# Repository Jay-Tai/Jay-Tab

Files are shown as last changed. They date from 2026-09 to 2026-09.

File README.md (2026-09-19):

# The Jay-Tab!

The Jay-Tab!
The Jay-Tab is one of my biggest personal projects! I made it to use it as a small screen to keep on my desk!

I made this project mainly out of personal interest. As to get the money to make this project in real life, I used [Hack club's stardance program!](https://stardance.hackclub.com/)

## Features!

There are many features that are packed into Jay-Tab:

- Beautifully 3D-Printed case!
- 2-Layer PCB enclosing all the hardware!
- Running on the ESP32-S3 WROOM
- 7.5" E-Ink touchscreen display to hold all the features of the Jay-Tab!
- <b>Home screen</b> that shows all you need to know at a glimpse
- <b>Calendar screen</b> that shows all the events happening in your day!
- <b>Timer screen</b> that has a timer that you can play a timer on a dedicated screen on your desk!
- <b>Home control screen</b> that is based off the Govee API, letting you toggle your lights, and change the color!

## CAD

The CAD model is from OnShape. It is made so the screen takes up 95% of the project, along with a stem that has weights inside of it to hold the Jay-Tab.

There are multiple parts, that are all going to be held using multiple screws. The power button is on the right side stem of the project.

### Important note about the CAD!

There is a part in the CAD that is CNCed. The bottom weight is CNCed to make sure that the Jay-Tab is able to stay upright, while also giving a premium feel through weight.There is also another laser-cuttable rubber part that goes on the bottom to stop it from moving.

The Jay-Tab!

## PCB



The PCB is the main hub of the entire project. It is in charge of making the OLED work, running code, powering the project, and the switches. It runs based off of the ESP32-S3 WROOM.

The following image is the schematic:

The schematic

And this is the PCB:
The schematic

## Firmware

The firmware for the project is based off of [python](https://www.python.org/) coding language. I made the UI Drawing Interface by myself, as I couldn't find any good libraries that are simple, and are able to support E-Ink Displays. The firmware includes the following:

- Home page that has a glimpse of your entire day with upcoming events, time, and quick controls.
- Calendar panel that is connected to your Google Calendar that shows all your events in a day
- Timer panel that allows you to create timers
- Smart home panel that connects to the Govee API, allowing you to toggle and change the color of your Govee lights.

Here is what the pages look like when connected to my APIs:

### Home Page:

The schematic

### Calendar:

The schematic

### Timer:

The schematic

### Home Control:

The schematic

## Quick Start

To make your own Jay-Tab, it is <b>crucial</b> that you follow these steps so that everything works with your environment!

<u>1: Create your Google Calendar API!</u>
The first step to making your own Jay-Tab is to create your own Google Calendar API. You can use the Google Cloud Calender API by clicking [here](https://console.cloud.google.com/marketplace/product/google/calendar-json.googleapis.com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). Download the file that has your key, and rename it to <i>calendar_desktop_credentials.json</i>

<u>2: Create your Govee API!</u>
The second step is to create the Govee API! Use the [following guide](https://developer.govee.com/docs/getting-started) to create your own govee API!

Once you get the Govee API, put it in under "apikey"

<u>3: Change your home screen name!</u>
To change the name on the Home Screen, use the adobe illustrator file that is attached under the software folder of the Jay-Tab. This will let you change the name from my name (Jay) to whatever it is!

# BOM

To make your own Jay-Tab, use the BOM under /bom.csv! :D

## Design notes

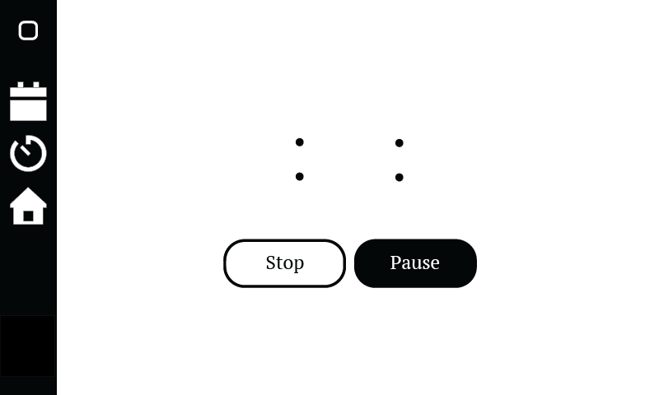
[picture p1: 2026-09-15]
Software/Raw images/New screens/Timer Running.png

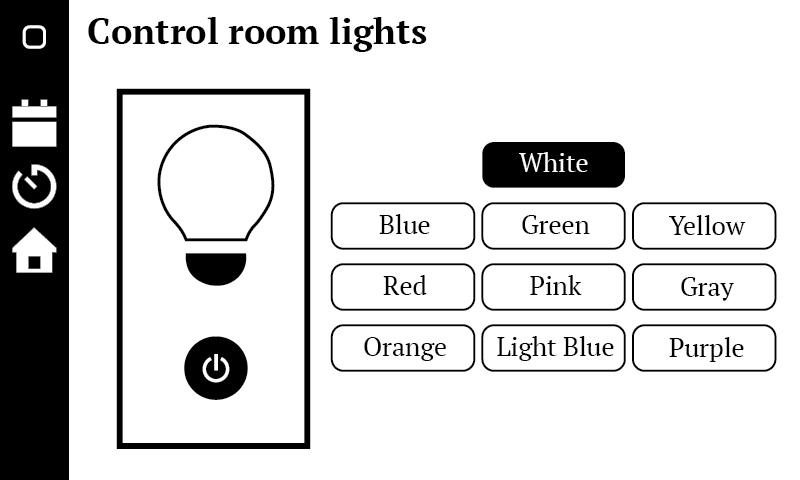
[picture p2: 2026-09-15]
Software/Raw images/New screens/Calendar - Software.png

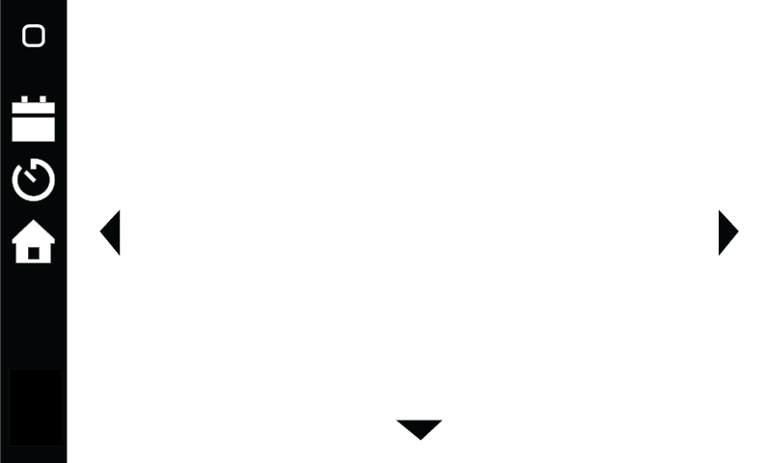
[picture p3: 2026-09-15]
Software/Raw images/New screens/Calendar over 6.png

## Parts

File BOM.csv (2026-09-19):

Item | Description | Quantity | Item Total Price + Tax | Supplier | URL
7.5-Inch Touch E-Paper E-Ink Display | Display | 1 | $57.00 | Goodisplay | https://buy-lcd.com/products/gdey075t7-t01
ESP32-S3-WROOM-1-N16R8 | MCU | 1 | $8.54 | Digikey | https://www.digikey.ca/en/products/detail/espressif-systems/ESP32-S3-WROOM-1-N8/15200089
12-pin 2.5mm pitch JST-XH Horizontal Through-Hole Connector | Display connector to PCB from HAT | 1 | $0.69 | Digikey | https://www.digikey.ca/en/products/detail/jst-sales-america-inc/S12B-XH-A/1651019
EC11 Switch Rotary Encoder | Rotary Encoder | 1 | $3.04 | Digikey | https://www.digikey.ca/en/products/detail/bourns-inc/PEC11R-4220F-S0024/4499660
SPDT Latching Push Switch | Power button | 1 | $9.51 | Amazon | https://www.amazon.ca/Gebildet-Stainless-Latching-12V-24V-Waterproof/dp/B07P7SXCP3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
Custom PCB Printing | Backend PCB | 1 | $9.94 | JLCPCB | https://ibb.co/8nVgBxCD
DESPI-C02 E-Ink Display HAT | Display adapter | 1 | $20.82 | Goodisplay | https://www.good-display.com/product/516.html
CNC for weight | Weight stem | 1 | $79.50 | PcbWay | https://postimg.cc/TywTsFk9
Digikey - FedEx International Priority | Shipping | 1 | $10.73 | Digikey + FedEx | https://ibb.co/r2qRh172
JLC Product Shipping | Shipping | 1 | $10.63 | JLCPCB | https://ibb.co/3Y4qh31H
6-Pin FPC Breakout Board | Amazon | 1 | $8.88 | Amazon | https://www.amazon.ca/uxcell-Converter-Couple-Extend-Adapter/dp/B07RWRK4WX
Printing Legion 3DP Fee | 3D Printing fee | 1 | $20 | Hack Club | N/A
USB-C 12-Pin SMD | USB-C | 1 | $1.77 | Digikey | https://www.digikey.ca/en/products/detail/on-shore-technology-inc/USB-CB16HTBTR/18649611
5.2kΩ Resistor | Resistor type 1 | 2 | $0.36 | Digikey | https://www.digikey.ca/en/products/detail/stackpole-electronics-inc/CF14JT10K0/1741265
10uF Capacitor | Capacitor | 2 | $8.59 | Digikey | https://www.digikey.ca/en/products/detail/vishay-beyschlag-draloric-bc-components/MAL202138109E3/262969
4.7kΩ Resistor | Resistor type 2 | 2 | $0.36 | Digikey | https://www.digikey.ca/en/products/detail/stackpole-electronics-inc/CF14JT10K0/1741265
AMS1117-3.3 Voltage Regulator | 3.3V Voltage Regulator | 1 | $0.53 | Digikey | https://www.digikey.ca/en/products/detail/umw/AMS1117-3-3/17635254
1569-22-1-0500-001-1-TS | Wire | 5 Feet | $4.28 | Digikey | https://www.digikey.ca/en/products/detail/cnc-tech/1569-22-1-0500-001-1-TS/7065706
Laser-Cuttable Rubber Stamp Sheet | Rubber Sheet | 1 | $13.51 | Amazon | https://www.amazon.ca/Frddiud-Rubber-Engraving-Machine-Supplies/dp/B0CC4PDZPF/ref=sr_1_7?sr=8-7&th=1
Total: | $268.69

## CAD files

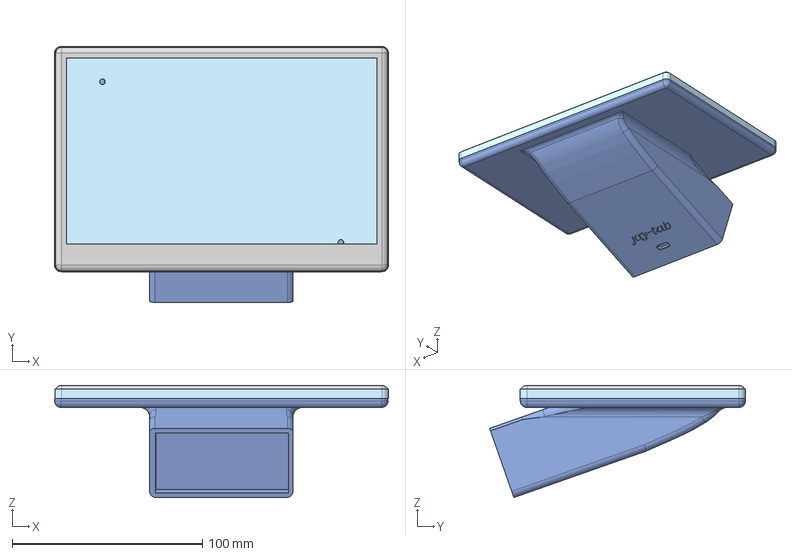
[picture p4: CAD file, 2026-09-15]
CAD/Jay-Tab Assembly.step
175.6 x 134.5 x 58.9 mm

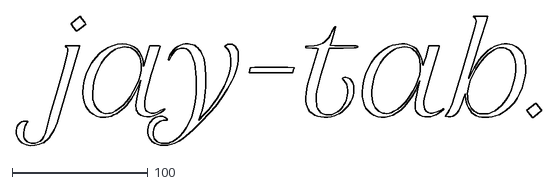
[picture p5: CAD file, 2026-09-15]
Logo/Logo.dxf
386.9 x 95.1

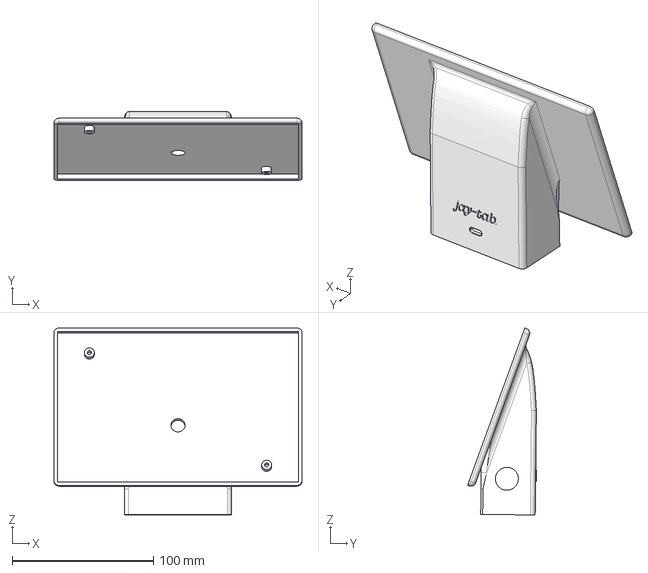
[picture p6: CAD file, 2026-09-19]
Production/Bottom Piece.step
175.4 x 48.7 x 132.2 mm

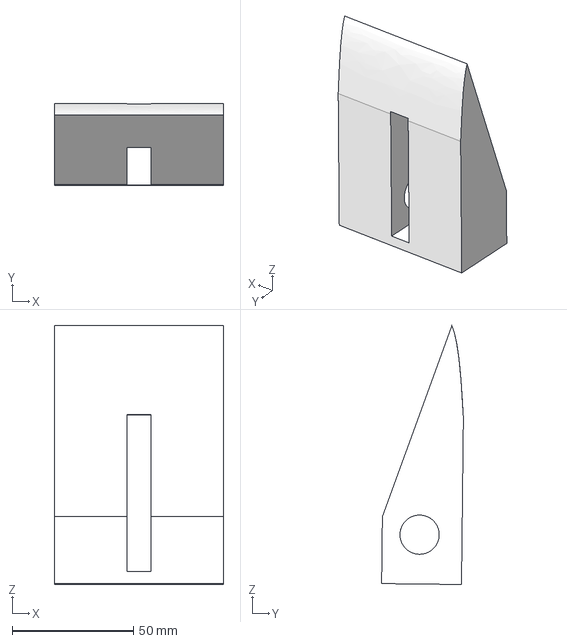
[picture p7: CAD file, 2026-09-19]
Production/Bottom weight.step
69.9 x 33.7 x 106.9 mm

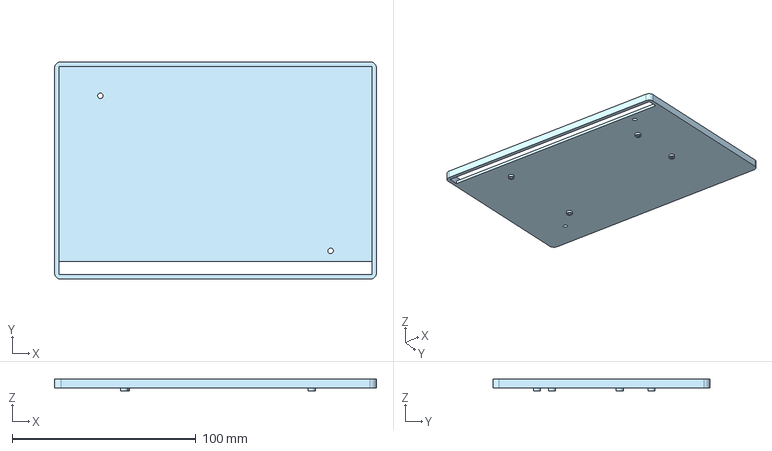
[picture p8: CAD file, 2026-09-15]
Production/Middle Piece.step
175.4 x 118.4 x 6.50 mm

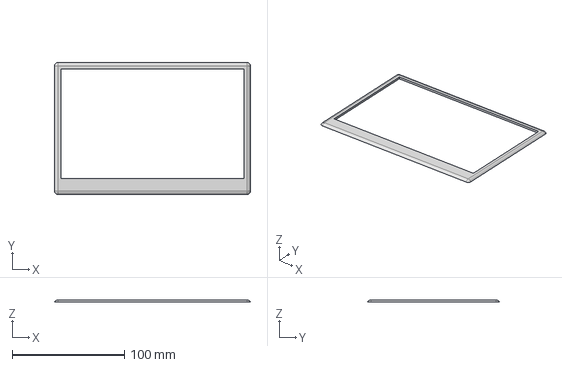
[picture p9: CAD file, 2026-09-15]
Production/Top Piece.step
174.7 x 117.7 x 2.00 mm

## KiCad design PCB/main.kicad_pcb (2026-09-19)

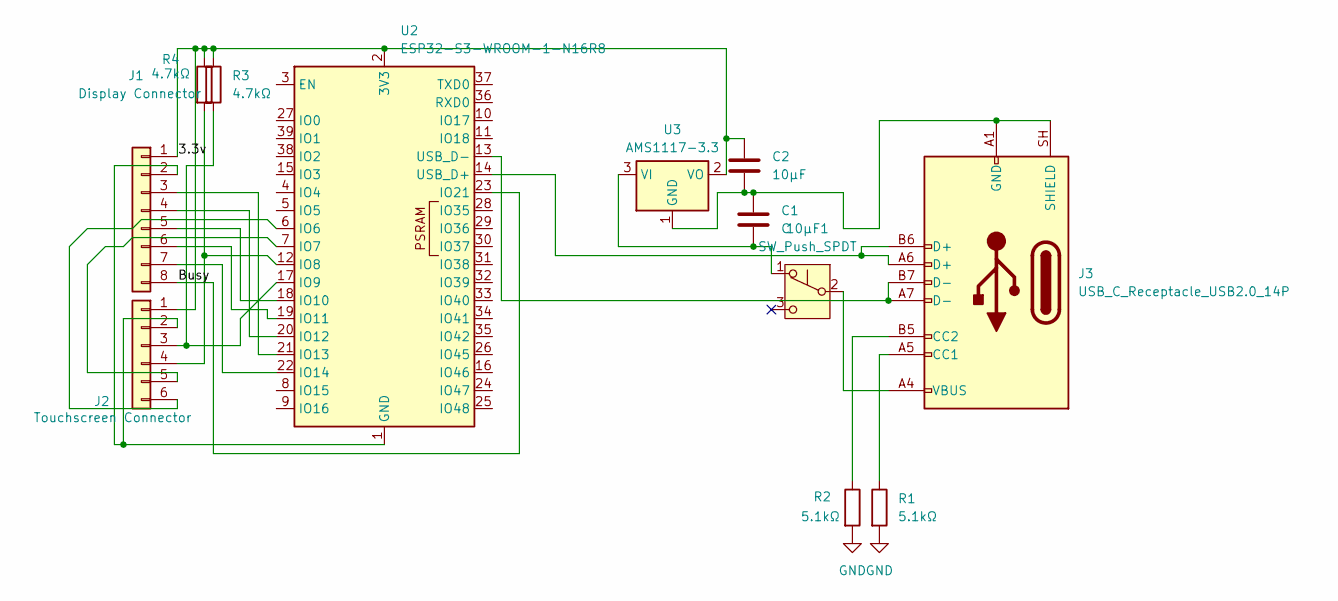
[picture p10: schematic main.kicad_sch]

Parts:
10μF1: SW_Push_SPDT; External_SPDT_Switch
C1: C; C_Disc_D5.0mm_W2.5mm_P5.00mm
C2: 10μF; C_Disc_D5.0mm_W2.5mm_P5.00mm
J1: Display Connector; PinSocket_1x08_P2.54mm_Vertical
J2: Touchscreen Connector; FPC_6pc_0.5mm_Breakout_Board_Pins
J3: USB_C_Receptacle_USB2.0_14P; External_USB_C
R1, R2: 5.1kΩ; R_Axial_DIN0207_L6.3mm_D2.5mm_P7.62mm_Horizontal
R3, R4: 4.7kΩ; R_Axial_DIN0207_L6.3mm_D2.5mm_P7.62mm_Horizontal
U2: ESP32-S3-WROOM-1-N16R8; ESP32-S3-WROOM-1
U3: AMS1117-3.3; SOT-223-3_TabPin2

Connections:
/3.3v: C2.2, J1.1, J2.1, R3.1, R4.1, U2.2 (3V3), U3.2 (VO)
/Busy: J1.8, U2.23 (IO21)
GND: R1.2, R2.2
unnamed: 10μF1.1 (A), C1.1, U3.3 (VI)
unnamed: 10μF1.2 (B), J3.A4 (VBUS), J3.A9 (VBUS), J3.B4 (VBUS), J3.B9 (VBUS)
unnamed: J1.2, J2.2, U2.1 (GND), U2.40 (GND), U2.41 (GND)
unnamed: J1.3, U2.21 (IO13)
unnamed: J1.4, U2.20 (IO12)
unnamed: J1.5, U2.18 (IO10)
unnamed: J1.6, U2.19 (IO11)
unnamed: J1.7, U2.22 (IO14)
unnamed: J2.3, R3.2, U2.17 (IO9)
unnamed: J2.4, R4.2, U2.12 (IO8)
unnamed: J2.5, U2.7 (IO7)
unnamed: J2.6, U2.6 (IO6)
unnamed: J3.A5 (CC1), R1.1
unnamed: J3.B5 (CC2), R2.1
unnamed: C1.2, C2.1, J3.A1 (GND), J3.A12 (GND), J3.B1 (GND), J3.B12 (GND), J3.SH (SHIELD), U3.1 (GND)
unnamed: J3.A6 (D+), J3.B6 (D+), U2.14 (USB_D+)
unnamed: J3.A7 (D-), J3.B7 (D-), U2.13 (USB_D-)

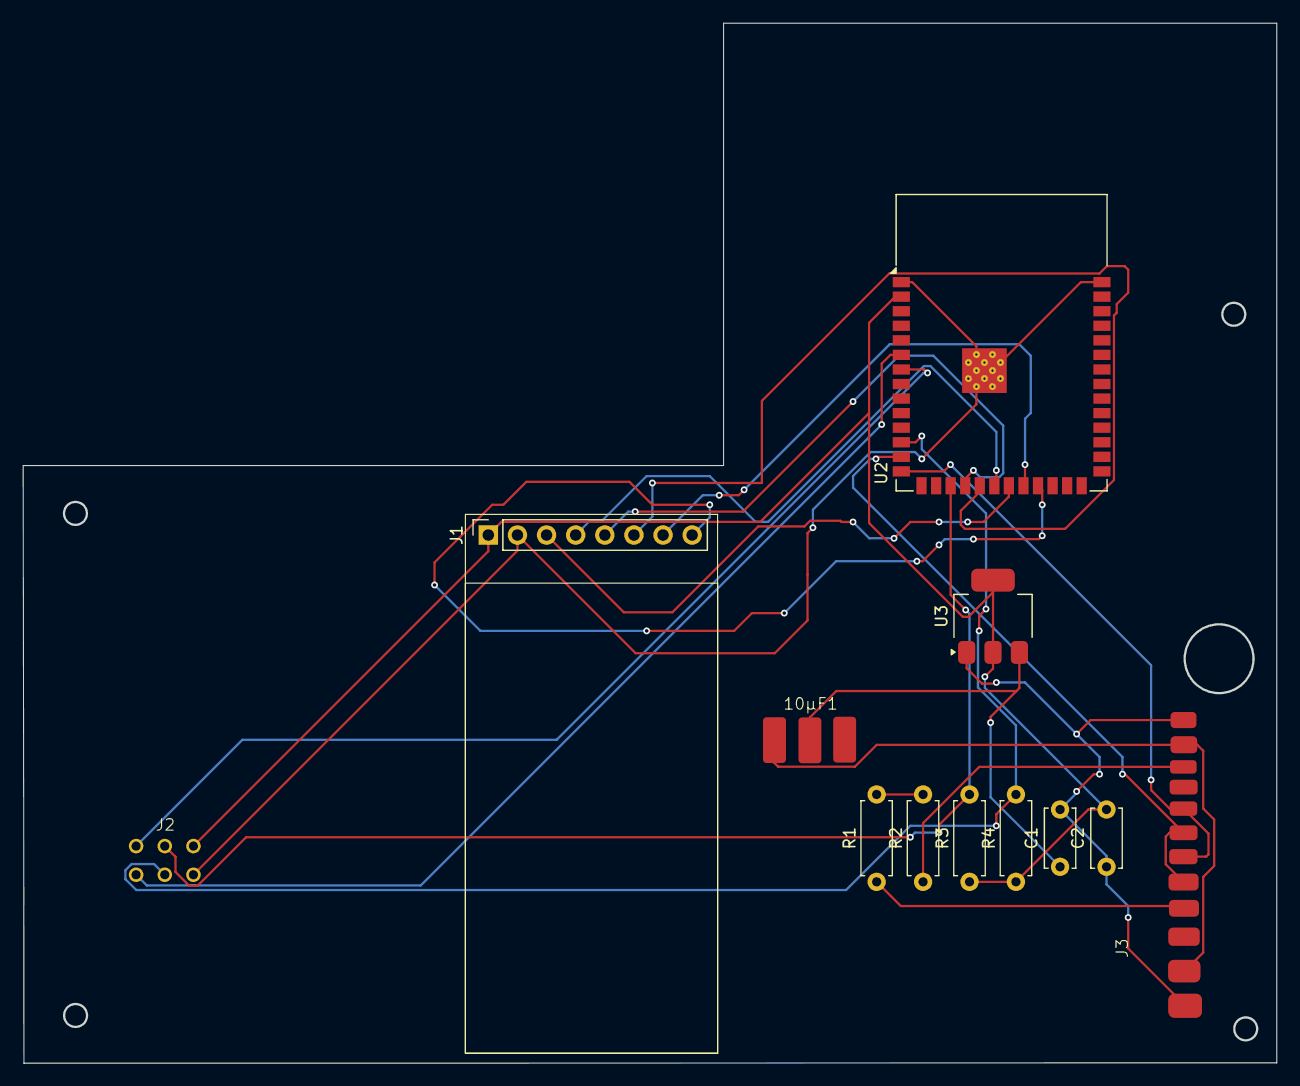
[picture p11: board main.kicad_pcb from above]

Board: 2 copper layers, 109.3 x 90.7 mm, 12 parts (0 on the bottom side), 20 nets.

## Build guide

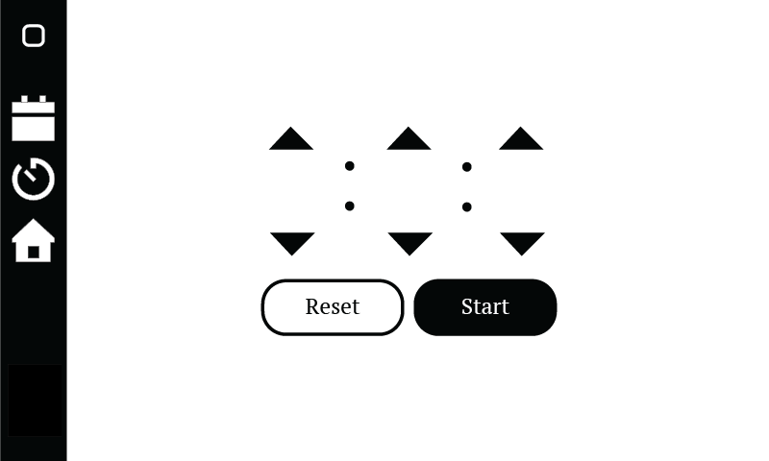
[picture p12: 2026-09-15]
Software/Raw images/New screens/Timer Setup.png

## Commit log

2026-09-15 Uploading all files part 1
    [Logo.dxf, main.kicad_pcb, main.kicad_sch]
2026-09-15 Uploading all files part 2
    [Bottom Piece.step, Bottom Weight.step, Jay-Tab Assembly.step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]
2026-09-19 Add the BOM
    [BOM.csv]
2026-09-19 Get rid of old bottom piece
    [Bottom Piece.step]
2026-09-19 Get rid of old bottom weight
    [Bottom Weight.step]
2026-09-19 Add new bottom part files
    [Bottom piece.step, Bottom weight.step]
2026-09-19 Add new gerbers
2026-09-19 Add new PCB files
    [main.kicad_pcb, main.kicad_sch]
2026-09-19 Deleting bottom piece
    Replacing with another version for better printing results
    [Bottom piece.step]
2026-09-19 Add new bottom piece
    [Bottom Piece.step]
